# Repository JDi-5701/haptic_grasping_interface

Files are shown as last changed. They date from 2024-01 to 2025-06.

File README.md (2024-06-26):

## 1. get the position of the knob

```bash
roslaunch knob_robot_control rosserial.launch
```
get the current position of the knob:
`rostopic echo /knob_state`

```bash
header: 
  seq: 10271
  stamp: 
    secs: 1712875324
    nsecs: 290215154
  frame_id: ''
mode: 
  data: ''
position: 
  data: -4
force: 
  data: 0.0
---
```

**The position should larger than 0, if not, please turn the knob to the right side.**

## 2. Force Feedback
```python
    def publish_force(self, force=1.0) -> None:
        knob_command = KnobCommand()
        knob_command.text.data = "force"
        knob_command.tcp_force.data = float(force) # (0.0 - 2.0) is a good choice
        self.knob_command_pub.publish(knob_command)
```

If you want no force feedback, set the force less than zero. 

**IN FORCE FEEDBACK MODE,  PLEASE KEEP HANDS ON THE KNOB, OTHERWISE THE KNOB WILL ROTATE UNCONTROLLABLY!!!**

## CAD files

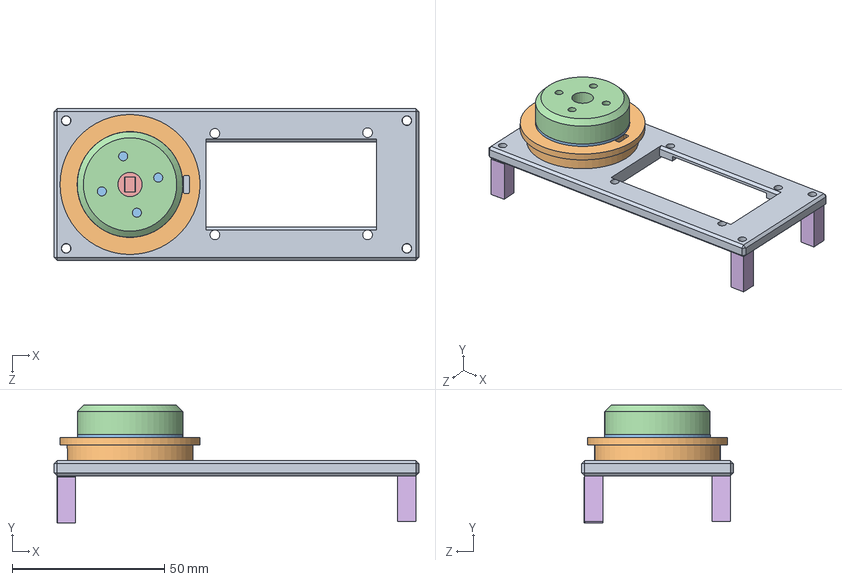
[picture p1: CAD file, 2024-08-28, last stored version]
models/SW/Assem1.SLDASM
120.0 x 38.6 x 50.0 mm
MotorTray
AS5600Connector
BLDMBottom
BLDCMotorTop
AS5600
TrayFoot x 4

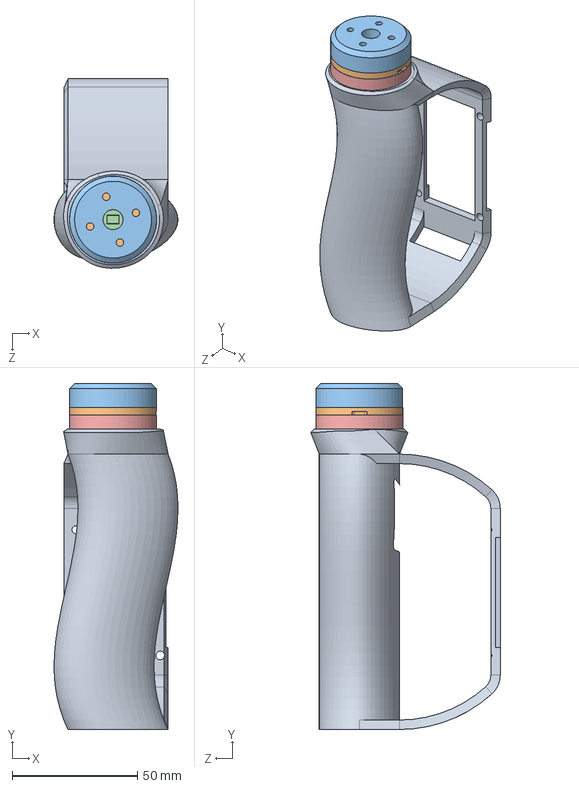
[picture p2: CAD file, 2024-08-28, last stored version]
models/SW/Assem2.SLDASM
49.5 x 138.2 x 75.7 mm
Stick
BLDMBottom
BLDCMotorTop
AS5600
AS5600Connector

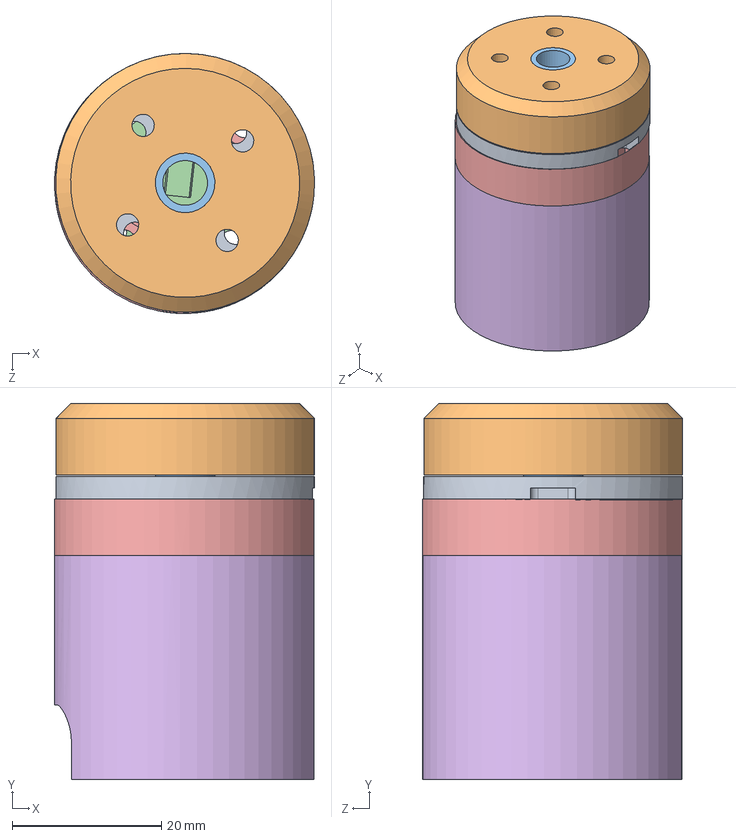
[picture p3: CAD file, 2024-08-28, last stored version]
models/SW/BLDCMotor.SLDASM
34.9 x 50.4 x 34.9 mm
BLDMBottom
BLDCMotorTop
BLDCMotorAxis
AS5600
AS5600Connector
AS5600Base

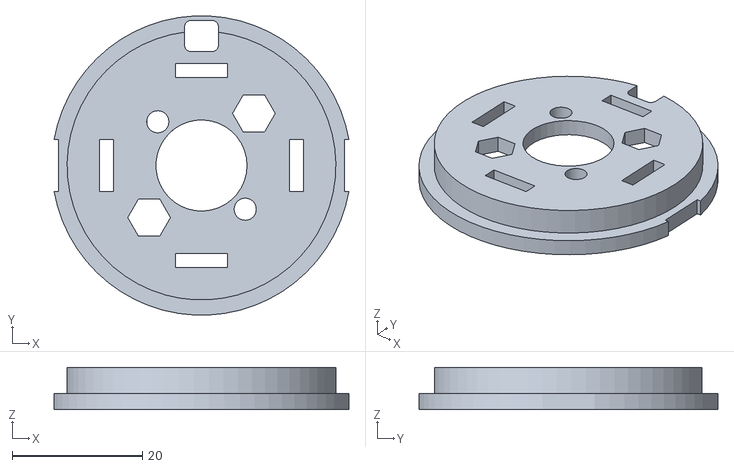
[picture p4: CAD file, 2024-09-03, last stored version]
models/STL/AS5600Connector_upper.STL
45.3 x 45.9 x 6.50

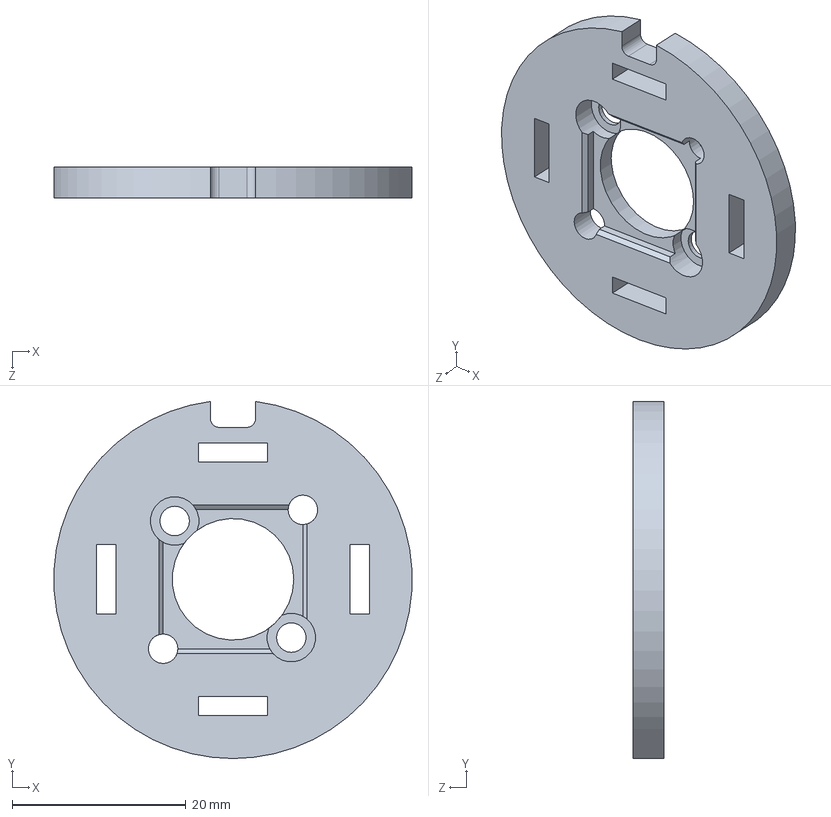
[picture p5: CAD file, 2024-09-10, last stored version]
models/SW/AS5600Connector_lower.SLDPRT
41.2 x 41.1 x 3.60 mm

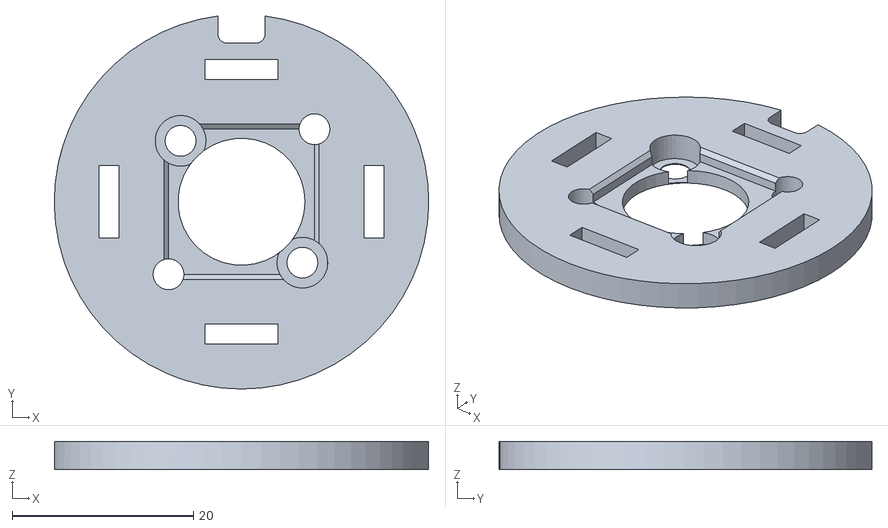
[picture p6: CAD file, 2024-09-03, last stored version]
models/STL/AS5600Connector_lower.STL
41.3 x 41.1 x 3.10

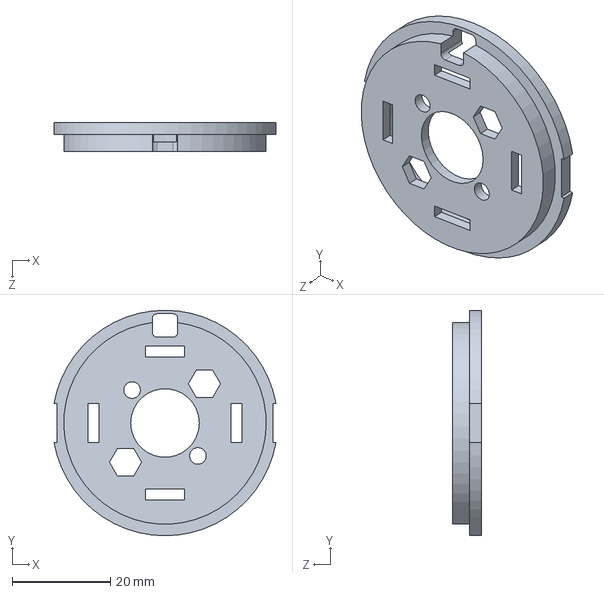
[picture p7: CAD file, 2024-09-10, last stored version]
models/SW/AS5600Connector_upper.SLDPRT
45.3 x 46.0 x 6.00 mm

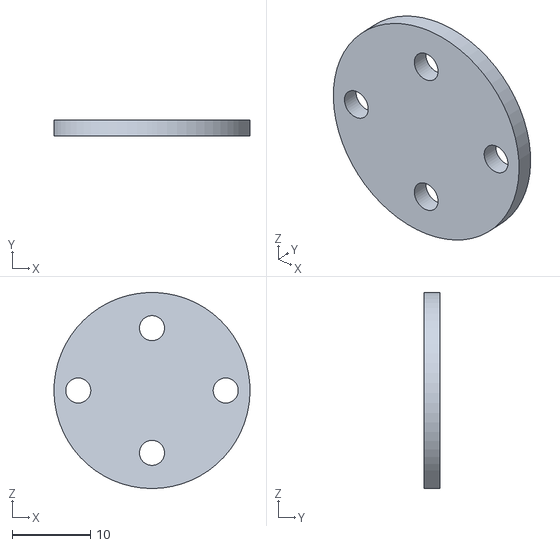
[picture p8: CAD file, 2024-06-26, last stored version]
models/STL/HoleTest.STL
25.0 x 2.00 x 25.0

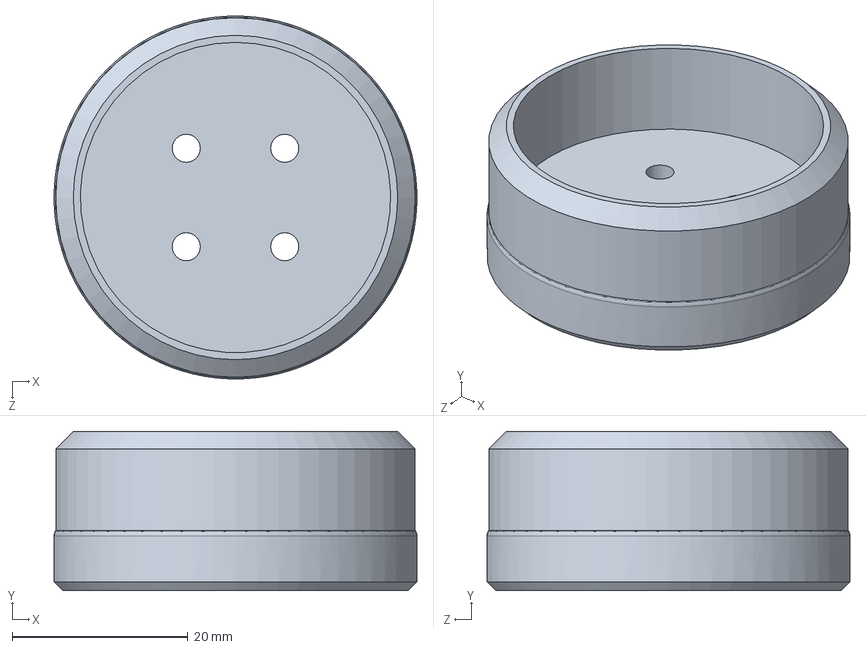
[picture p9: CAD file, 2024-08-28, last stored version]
models/SW/motor_lid.SLDPRT
41.3 x 18.1 x 41.3 mm

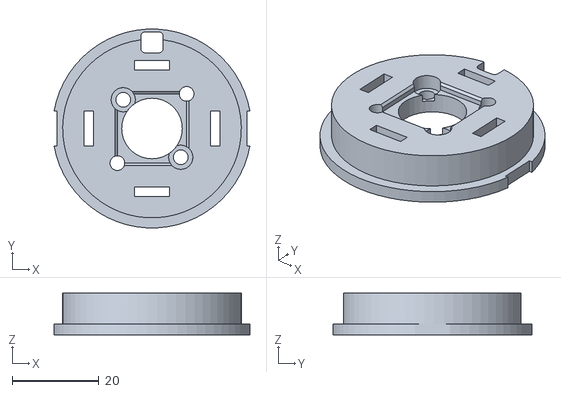
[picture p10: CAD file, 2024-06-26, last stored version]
models/STL/AS5600Connector.STL
45.3 x 45.9 x 9.60

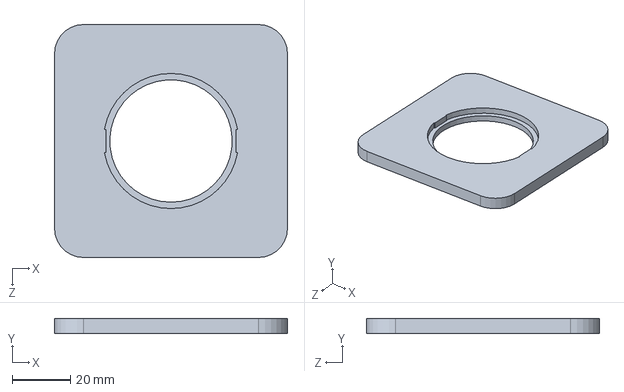
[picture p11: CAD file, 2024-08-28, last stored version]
models/SW/ControlBox_lid_rec.SLDPRT
80.0 x 5.00 x 80.0 mm

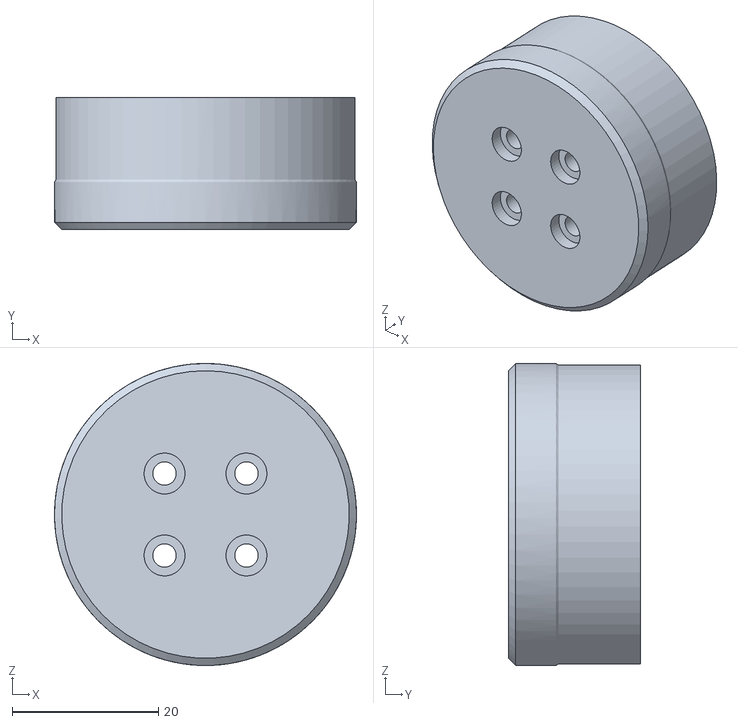
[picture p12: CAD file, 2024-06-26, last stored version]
models/STL/motor_lid.STL
41.3 x 18.1 x 41.3

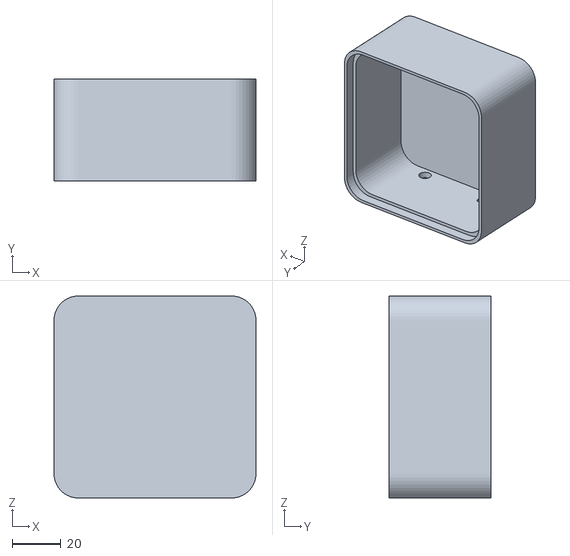
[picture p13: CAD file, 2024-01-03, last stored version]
models/STL/ControlBox_wall_rec.STL
83.0 x 42.0 x 83.0

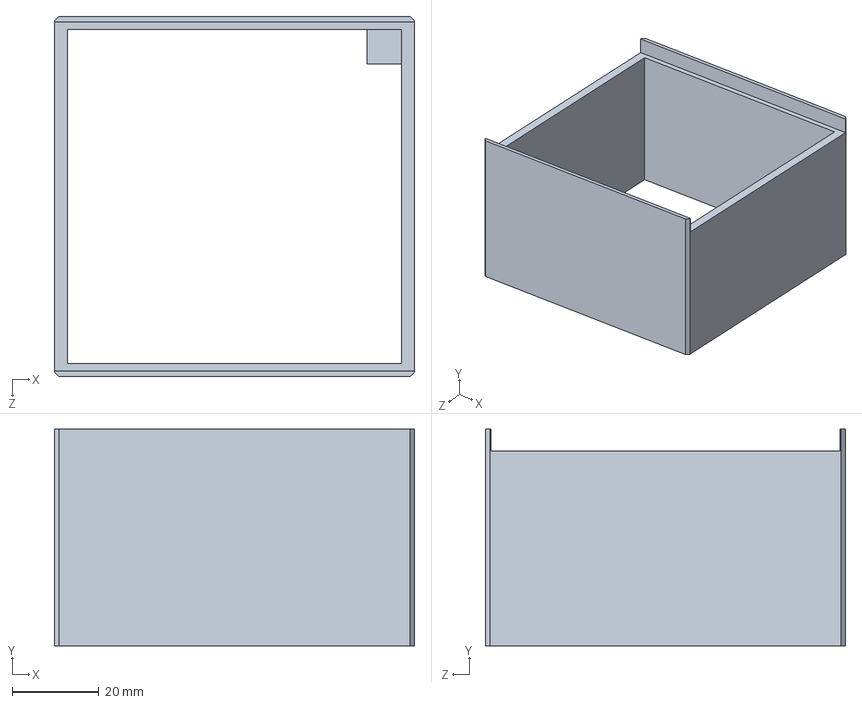
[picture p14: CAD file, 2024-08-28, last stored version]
models/SW/ControlBox_wall.SLDPRT
83.0 x 50.0 x 83.0 mm

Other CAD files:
models/SW/Fortiss_knob_v2.0.SLDASM
models/SW/Assem3.SLDASM
models/STL/ControlBox_lid_rec.STL
models/SW/BLDCMotorAxis.SLDPRT
models/SW/AS5600.SLDPRT
models/SW/AS5600Base.SLDPRT
models/SW/AS5600Connector.SLDPRT
models/SW/BLDCMotorTop.SLDPRT
models/SW/BLDMBottom.SLDPRT
models/SW/ControlBox_buttom.SLDPRT
models/SW/ControlBox_buttom_rec.SLDPRT
models/SW/ControlBox_lid.SLDPRT
models/SW/ControlBox_wall_rec.SLDPRT
models/SW/Fake_FT_sensor.SLDPRT
models/SW/KnobBase.SLDPRT
models/SW/KnobButtom.SLDPRT
models/SW/MagnetHolder.SLDPRT
models/SW/MotorTray.SLDPRT
models/SW/TrayFoot.SLDPRT

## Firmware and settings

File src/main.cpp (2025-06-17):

/*
 * This file is subject to the terms and conditions defined in
 * file 'LICENSE', which is part of this source code package.
 *
 *    Copyright (c) 2023 fortiss GmbH, Xiangyu Fu
 *    All rights reserved.
 */
#include <Arduino.h>
#include <SimpleFOC.h>

#include "motor_task.h"
#include "wifi_task.h"
#include "task.h"

static MotorTask motor_task(0);
static WifiTask wifi_task(0, motor_task);

void setup() {
    // Initialize serial communication
    Serial.begin(115200);
    delay(1000);  // Give time for serial to initialize
    Serial.println("\n\nStarting...");
    Serial.println("Testing serial output...");
    Serial.flush();
    
    // Initialize tasks
    wifi_task.begin();
    motor_task.begin();
    // interface_task.begin();
    
    // Start the scheduler
    //vTaskStartScheduler();
}

void loop() {
    // Not used - FreeRTOS scheduler handles task execution
}

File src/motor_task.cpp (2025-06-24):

/*
 * This file is subject to the terms and conditions defined in
 * file 'LICENSE', which is part of this source code package.
 *
 *    Copyright (c) 2023 fortiss GmbH, Xiangyu Fu
 *    All rights reserved.
 */
#include <SimpleFOC.h>

#include "motor_task.h"

// #### 
// Hardware-specific motor calibration constants.
// Run calibration once at startup, then update these constants with the calibration results.
static const float ZERO_ELECTRICAL_OFFSET = 2.35;
static const Direction FOC_DIRECTION = Direction::CW;
static const int MOTOR_POLE_PAIRS = 11;
// ####


MotorTask::MotorTask(const uint8_t task_core) : Task("Motor", 2500, 1, task_core) {
    Serial.println("MotorTask constructor start");
}

MotorTask::~MotorTask() {}

MagneticSensorI2C encoder = MagneticSensorI2C(AS5600_I2C);
TwoWire I2Cone = TwoWire(0);

// Merkel mechanism state
bool merkel_active = false;
uint64_t merkel_start_time = 0;
constexpr float MERKEL_TRIGGER_THRESHOLD = 1.0f;
constexpr float MERKEL_FORCE_N = 6.0f;
constexpr uint64_t MERKEL_DURATION_US = 500000; // 0.5 seconds
float merkel_delta = 1.0f;  // to be initialized in run()

bool isInContact(float current_force) {
    static bool IN_CONTACT = false;
    // 判断是否接触
    static float prev_force = 0.0f;
    
    if (prev_force <= MERKEL_TRIGGER_THRESHOLD &&
        current_force > MERKEL_TRIGGER_THRESHOLD) {
            IN_CONTACT = true;
    } else if (current_force < MERKEL_TRIGGER_THRESHOLD) {
        IN_CONTACT = false;
        }
    
    prev_force = current_force;

    return IN_CONTACT;
}

float applyMerkelMechanism(float current_force) {
    static bool merkel_active = false;
    static uint64_t merkel_start_time = 0;
    uint64_t now_us = micros();

    // 在外部触发时调用此函数才算激活，内部只计时
    if (!merkel_active) {
        merkel_active = true;
        merkel_start_time = now_us;
    }

    if (now_us - merkel_start_time <= MERKEL_DURATION_US) {
        return merkel_delta;
    } else {
        merkel_active = false;
        return 0.0;
    }
}

float applyPacinianMechanism(float gripper_force) {
    uint64_t now_us = micros();
    // 参数设定
    constexpr float PACINIAN_FREQ = 150.0f;        // 固定频率 (Hz)
    constexpr float DEFARULT_AMPLITUDE = 0.1f;          // 最大振幅
    constexpr float AMPLITUDE_FORCE_RATIO= 0.1f;

    static uint64_t pacinian_start_time = 0;

    if (pacinian_start_time == 0) {
        pacinian_start_time = now_us;
    }

    float t = (now_us - pacinian_start_time) / 1e6f; // 秒
    float pacinian_force = (DEFARULT_AMPLITUDE + AMPLITUDE_FORCE_RATIO *gripper_force ) * sinf(2.0f * PI * PACINIAN_FREQ * t);

    return pacinian_force;
}


float MotorTask::computeForceFeedback(float gripper_force) {
    // --- 可调参数 ---
    constexpr float FORCE_FEEDBACK_RATIO = 0.1f;
    constexpr float FORCE_OFFSET = 0.2f;
    constexpr float LOG_A = 1.0f;
    constexpr float LOG_B = 0.6f;
    constexpr float CLAMP_MIN = 0.0f;
    constexpr float CLAMP_MAX = 1.0f;
    static bool IN_CONTACT = false;

    float merkel_force;
    float pacinian_force;
    float gripper_force_with_merkel_with_pacinian;

    IN_CONTACT = isInContact(gripper_force);
    if (IN_CONTACT) {
        // 如果接触，应用 Merkel 和 Pacinian 机制
        //merkel_force = applyMerkelMechanism(gripper_force);
        merkel_force = 0.0f;
        pacinian_force = applyPacinianMechanism(gripper_force);
    } else {
        // 如果没有接触，直接返回原始力
        merkel_force = 0.0f;
        pacinian_force = 0.0f;
    }

    gripper_force_with_merkel_with_pacinian = gripper_force + merkel_force + pacinian_force;

    // 1. 线性预处理
    float force_input = FORCE_FEEDBACK_RATIO * (gripper_force_with_merkel_with_pacinian + FORCE_OFFSET);
    force_input = std::max(force_input, 0.0f);  // 忽略负值

    // 2. 非线性对数映射
    float force_human = LOG_A * logf(1.0f + LOG_B * force_input);

    // 4. 限幅
    if (force_human > 0.0f)
        force_human = std::min(CLAMP_MAX, std::max(CLAMP_MIN, force_human));
    else
        force_human = std::max(-CLAMP_MAX, std::min(-CLAMP_MIN, force_human));

    // 5. 输出方向（必要时反向）
    return force_human;
}

void MotorTask::run(){

    pinMode(13, OUTPUT); // Using pin 13 instead of 12 for ESP32 compatibility
    digitalWrite(13, LOW); // Explicitly set to LOW

    motor.controller = MotionControlType::torque;
    motor.torque_controller = TorqueControlType::voltage;

    // motor setup
    driver.voltage_power_supply = 12;
    driver.init();
    motor.linkDriver(&driver);

    // Initialize the I2C bus
    I2Cone.setPins(21, 22);
    encoder.init(&I2Cone);
    motor.linkSensor(&encoder);

    motor.voltage_limit = 6;
    motor.velocity_limit = 1000;
    motor.pole_pairs = MOTOR_POLE_PAIRS;

    /* Calibration of motor and sensors*/
    
    motor.init();
    motor.controller = MotionControlType::torque;
    motor.torque_controller = TorqueControlType::voltage;
    motor.initFOC();

    motor.controller = MotionControlType::torque;
    motor.torque_controller = TorqueControlType::voltage;

    encoder.update(); // here is from the future version of SimpleFOC
    vTaskDelay(pdMS_TO_TICKS(10));

    float initial_poistion = encoder.getAngle();

    Serial.println("Motor ready!");
    tcp_force = 0.0;
    knob_state = 0;

    uint64_t last_cycle_start = micros();
    while (1)
    {

        int32_t current_force_id = force_id;
        uint64_t current_force_time = force_timestamp;
        float current_force = tcp_force;

        motor.loopFOC();

        // print current position, after checking the sensor reading is work well
    
        char str_angle[100];
        float encoder_angle = encoder.getAngle();    

        float angle_to_detent_center = encoder.getAngle() - initial_poistion;

        float torque = 0;
        if (fabsf(motor.shaft_velocity) > 600) {
            motor.move(0);
        } else {
            // Apply TCP force feedback
            //torque = motor.PID_velocity(-0.1 * tcp_force);
            motor_command = computeForceFeedback(current_force);

            // Serial.print("tcp_force: ");
            // Serial.print(tcp_force);
            // Serial.print("motor_command: ");
            // Serial.print(motor_command);

            motor.move(motor_command);

        }


        knob_state = int32_t(1000 * angle_to_detent_center);
        /* Serial.print("motor task knob state:");
        Serial.print(knob_state);
        Serial.print("\t");  */

        motor_torque = motor.voltage.q;

        
        // Serial.print("tcp_force: ");
        // Serial.print(tcp_force);
        // Serial.print("Applied voltage (V): ");
        // Serial.println(motor.voltage.q);

        // Serial.print("Controller type: ");
        // Serial.println((int)motor.controller);

        // Serial.print("Torque controller type: ");
        // Serial.println((int)motor.torque_controller);

        motor.monitor();
        
        vTaskDelay(pdMS_TO_TICKS(1));


        uint64_t now = micros();
        uint64_t cycle_time = now - last_cycle_start;
        last_cycle_start = now;
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

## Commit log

2024-01-03 update repo
    [AS5600Connector.STL, ControlBox_lid_rec.STL, ControlBox_wall_rec.STL]
2024-06-26 update code
    [AS5600Connector.STL, HoleTest.STL, motor_lid.STL]
2024-08-28 update sw models(sw v.2023)
    [AS5600.SLDPRT, AS5600Base.SLDPRT, AS5600Connector.SLDPRT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]
2024-09-03 update models
    [AS5600Connector_lower.STL, AS5600Connector_upper.STL]
2024-09-03 auto commit at 09/0/224152633
    [AS5600Connector_lower.SLDPRT, AS5600Connector_lower.STL, AS5600Connector_upper.SLDPRT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]
2024-09-10 The motor can reverse its action, the P of PID has been changed to a constant
    [motor_task.cpp]
2024-11-27 Add current sensing.
2025-04-09 Add udp commnication.
    [AS5600.SLDPRT, AS5600Base.SLDPRT, AS5600Connector.SLDPRT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]
2025-06-16 Direct udp with force sensor. Unstable knob.
    [motor_task.cpp, wifi_task.cpp]
2025-06-17 Direct udp esp32 without motor viberation. 3505
2025-06-20 new esp32 with type c.
2025-06-20 Switch back to 3510. Add merkel and parcinian force.
